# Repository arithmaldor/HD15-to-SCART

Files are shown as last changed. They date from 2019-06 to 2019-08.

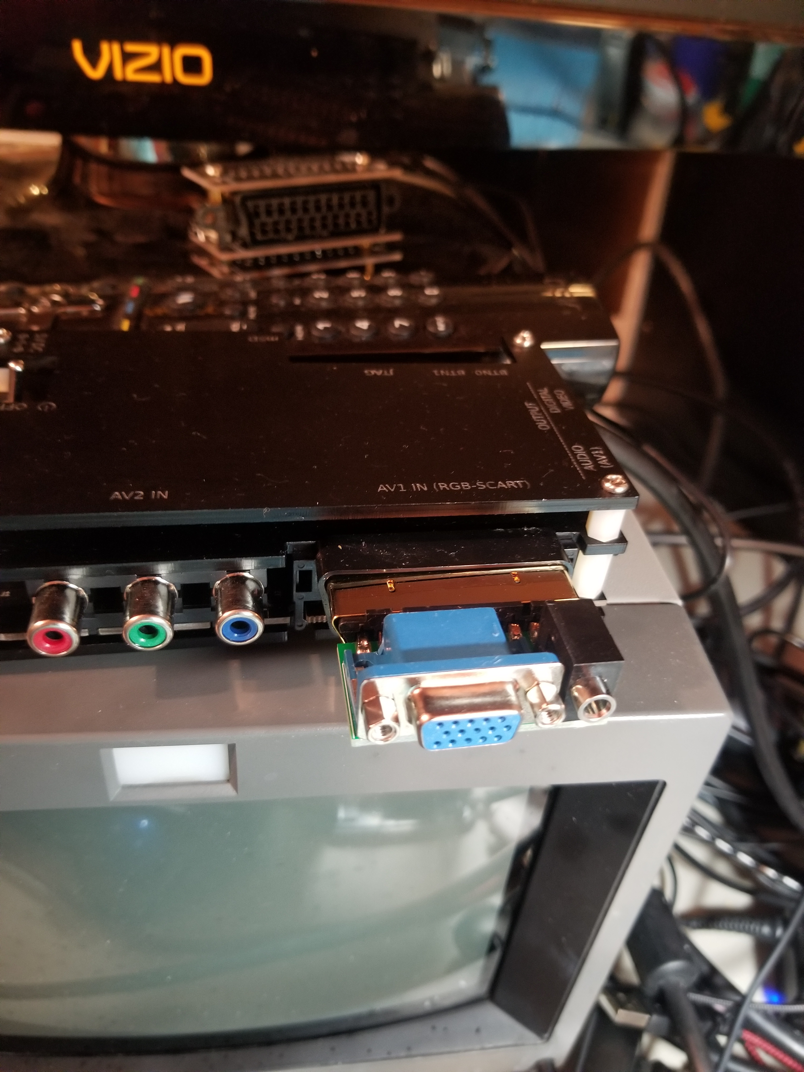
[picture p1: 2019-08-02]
Photos/20190723_003635.jpg

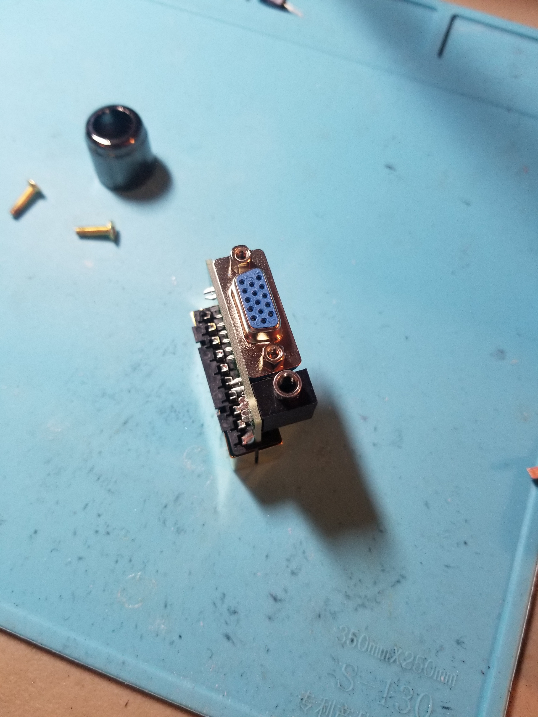
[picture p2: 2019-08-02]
Photos/20190723_003609.jpg

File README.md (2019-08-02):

# Copyright and Disclaimer
Copyright: Jacob Proctor

This documentation describes Open Hardware and is licensed under the
CERN OHL v. 1.2.

You may redistribute and modify this documentation under the terms of the
CERN OHL v.1.2. (http://ohwr.org/cernohl). This documentation is distributed
WITHOUT ANY EXPRESS OR IMPLIED WARRANTY, INCLUDING OF
MERCHANTABILITY, SATISFACTORY QUALITY AND FITNESS FOR A
PARTICULAR PURPOSE. Please see the CERN OHL v.1.2 for applicable
conditions

# VGA to SCART
This is a passive adapter that simply connects the RGB and sync pins from a VGA connector and the right and left audio pins from a 3.5mm jack to the corresponding pins on
a male SCART connector. It is unidirectional and cannot be used for VGA output from a SCART device. It does not convert RGBHV to RGBS or 31khz to 15khz or anything fancy like that.
# Uses
The main purpose of this board for me is to replace SCART cables with VGA cables. Using this adapter you can run a VGA cable from a breakout adapter to a gscartsw for example without
having to worry about making your own cables or having custom ones made. I'm sure that other uses can be found.
# BOM
There are only 3 parts so I thought I would just list them here instead of making a full BOM. Listed are digikey links but the parts are pretty common and it should be possible to substitute others, just compare datasheets for the footprints.
VGA Connector: https://www.digikey.com/product-detail/en/amphenol-icc-fci/ICD15S13E6GV00LF/609-2802-ND/1090326
Headphone Jack: https://www.digikey.com/product-detail/en/cui-inc/SJ1-3533NG/CP1-3533NG-ND/738701
SCART Connector: Any will do, console5.com has new ones and reclaimed ones.
New: https://console5.com/store/scart-plug-21-pin-male-cable-connector.html
Reclaimed: https://console5.com/store/reclaimed-scart-jp21-plug-21-pin-male-cable-connector.html
# Assembly
Use the photos for reference. Pin 20 of the SCART connector (the point) goes towards the left when looking at the top of the board. You can also solder a wire or component leg between the shield and the spare ground pin on the board.

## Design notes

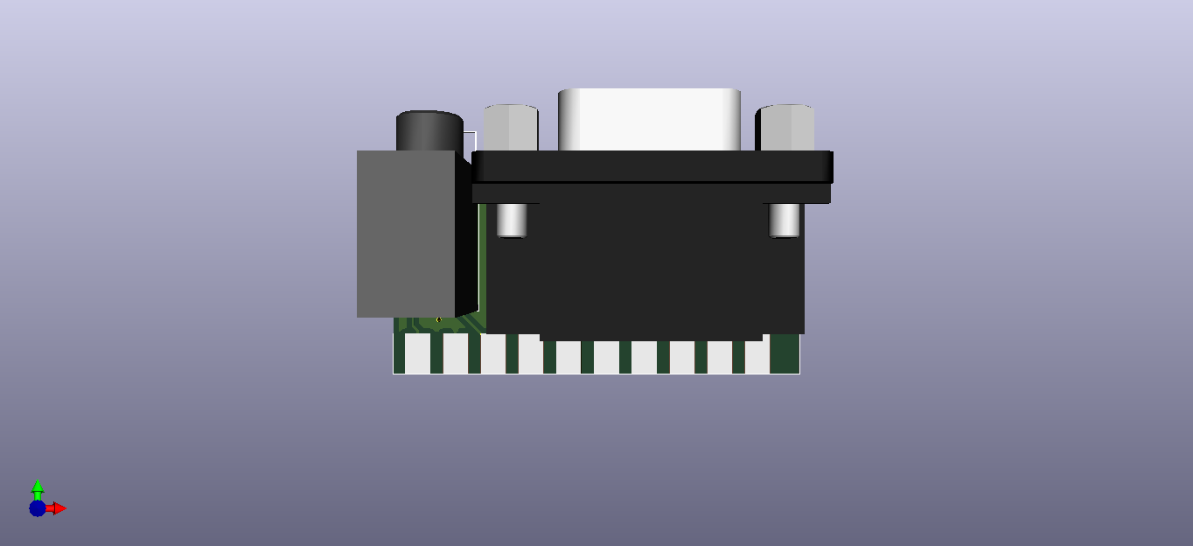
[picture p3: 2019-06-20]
Renders/Top View 3D.png

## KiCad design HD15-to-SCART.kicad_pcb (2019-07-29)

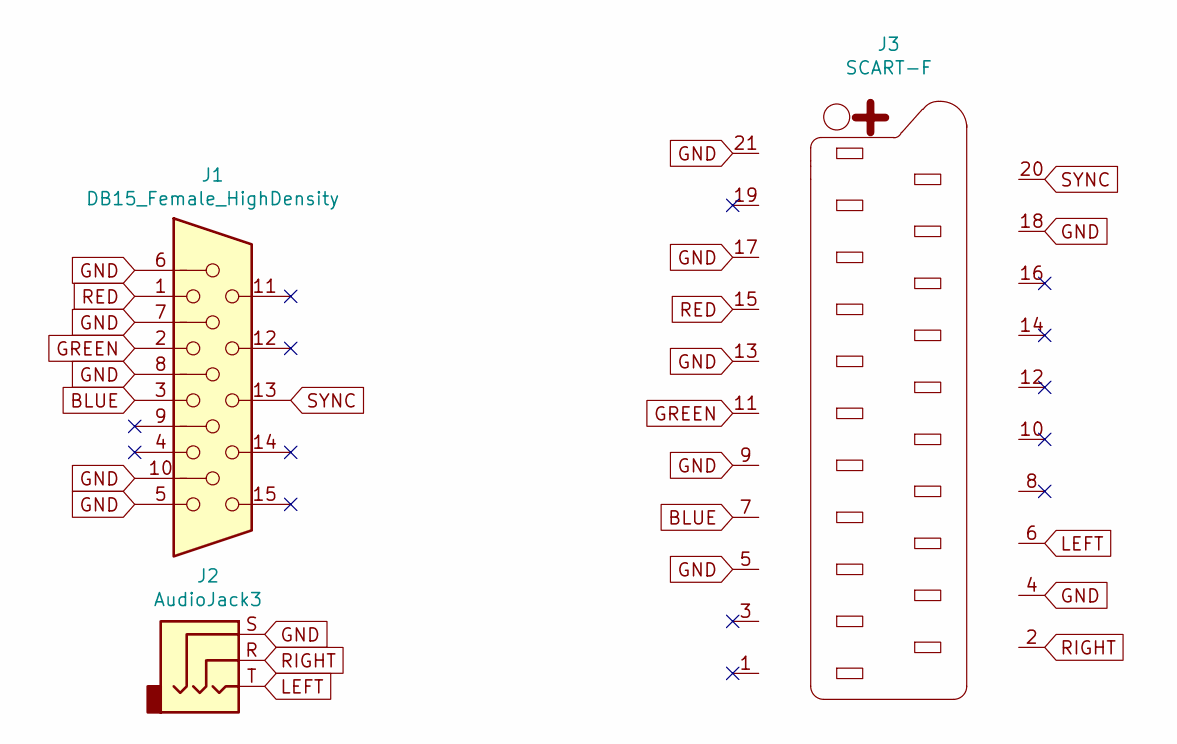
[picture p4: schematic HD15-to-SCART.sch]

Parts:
J1: DB15_Female_HighDensity; VGA
J2: AudioJack3; Tall_Skinny_Headphone_Universal_CUI_SJ1-353XNX
J3: SCART-F; MALE_SCART

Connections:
BLUE: J1.3, J3.7
GND: J1.0, J1.5, J1.6, J1.7, J1.8, J1.10, J2.S, J3.4, J3.5, J3.9, J3.13, J3.17, J3.18, J3.21
GREEN: J1.2, J3.11
LEFT: J2.T, J3.6
RED: J1.1, J3.15
RIGHT: J2.R, J3.2
SYNC: J1.13, J3.20

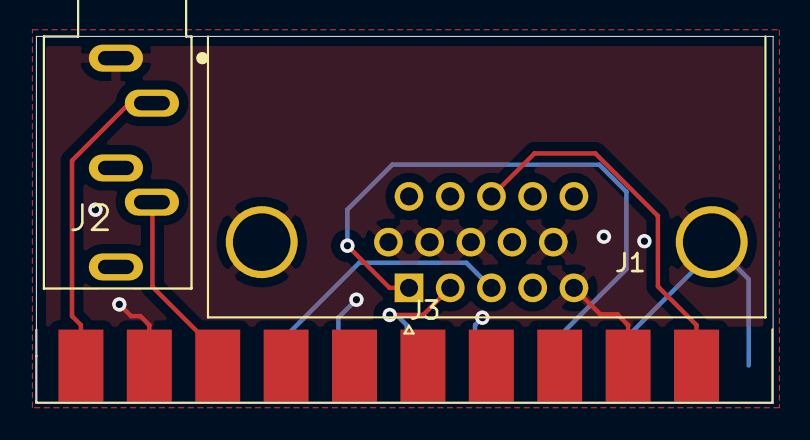
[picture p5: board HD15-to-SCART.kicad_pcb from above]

Board: 2 copper layers, 40.9 x 20.4 mm, 3 parts (0 on the bottom side), 7 nets.

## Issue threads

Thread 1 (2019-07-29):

headphone jack footprint

arithmaldor, 2019-07-29:
used the wrong one idiot, drills are not oval shaped and should be

arithmaldor, 2019-07-29:
fixed it

Closed 2019-07-29.

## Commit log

2019-06-12 Initial Commit
    Created repository, started brainstorming with schematic
    [HD15-to-SCART.kicad_pcb, HD15-to-SCART.sch]
2019-06-20 Finished schematic and designed pcb
    [HD15-to-SCART-B_Cu.gbl, HD15-to-SCART-B_Mask.gbs, HD15-to-SCART-B_SilkS.gbo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]
2019-06-25 Create gerber zip
2019-07-29 fixed headphone footprint, regenerated gerbers
    [HD15-to-SCART-B_Cu.gbl, HD15-to-SCART-B_Mask.gbs, HD15-to-SCART-B_SilkS.gbo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]
